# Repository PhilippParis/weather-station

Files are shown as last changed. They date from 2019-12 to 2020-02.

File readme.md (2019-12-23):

# ESP8266 Weather-Station

A simple battery powered Weather-Station using the ESP8266.

Transmits the current temperature periodically via 433MHz (range: ~5meters).  
Uses the same encoding as the 'LaCrosse TX2U Temperature Sensor'.

Publishes the temperature, humidity and pressure to OpenWeatherMap.org.  
Data is buffered in the RTC memory and published once per hour to preserve battery.

## Hardware

### Components

* ESP-12F ESP8266 Module
* LM3671 3.3V Buck Converter Breakout
* Adafruit HTU21D-F Temperature & Humidity Sensor
* BMP180 BOSCH Temperature Pressure Sensor 
* FS1000A 433MHz Transmitter

### Schematics

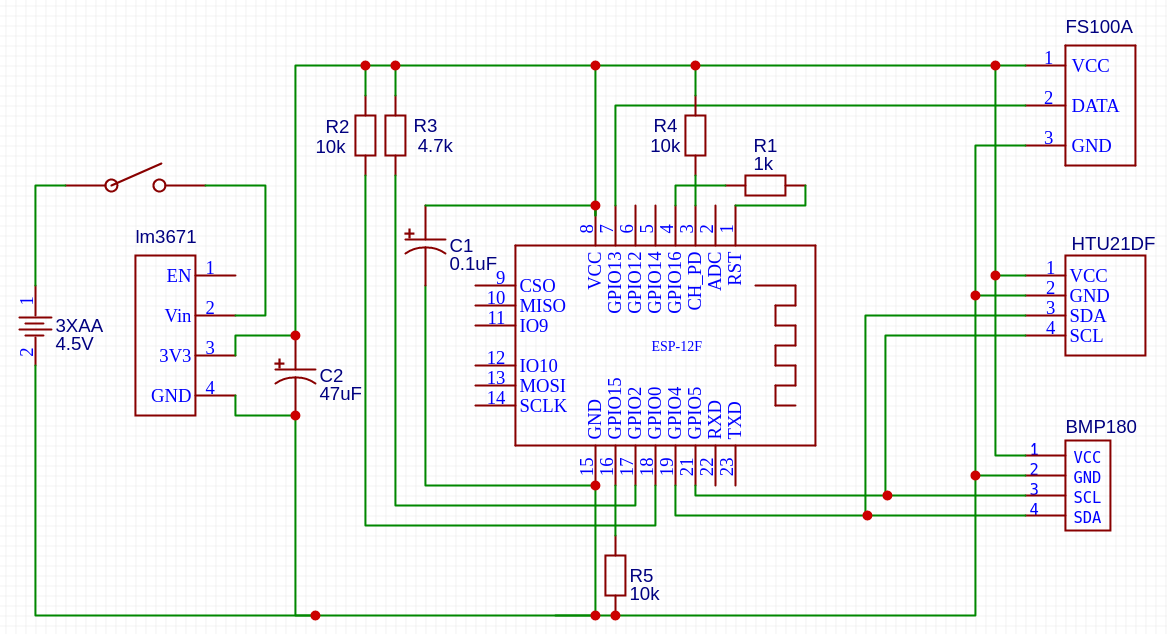
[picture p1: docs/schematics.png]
schematics


## Configuration
### secrets.h

```C++
#define SECRET_WIFI_SSID        "wifi_ssid"
#define SECRET_WIFI_PASSWD      "wifi_password"
#define SECRET_OWM_API_KEY      "open_weather_map_api_key"
#define SECRET_OWM_STATION_ID   "open_weather_map_station_id"
```

## Installation

### Arduino IDE Settings

#### Libaries
* Adafruit BMP085 Unified
* Adafruit HTU21DF Library
* NTPClient

#### Board
Additional Boards Manager URLS: http://arduino.esp8266.com/stable/package_esp8266com_index.json

* Board: Generic ESP8266 Module
* Flash Mode: DIO
* Flash Size: "1MB (FS: 512KB OTA: ~246KB)"

### Programmer Wiring
| Programmer  | ESP12 |
| ---- | --- |
| 3V3  | VCC |
| GND  | GND |
| TXD  | RXD |
| RXD  | TXD |
| GND  | GPIO0 (only when uploading) |

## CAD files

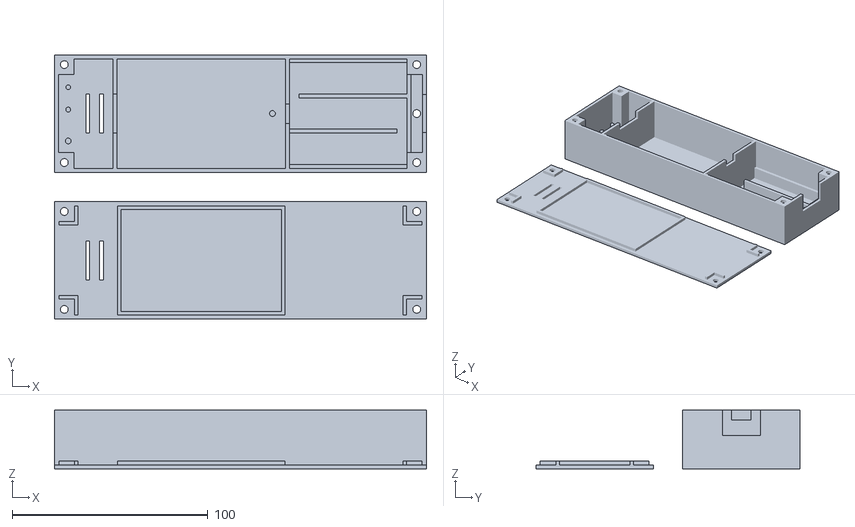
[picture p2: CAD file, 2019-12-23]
docs/case.stl
190.0 x 135.0 x 30.0

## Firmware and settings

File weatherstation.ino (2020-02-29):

#include <ESP8266WiFi.h>
#include <ESP8266HTTPClient.h>
#include <Wire.h>
#include <NTPClient.h>
#include <WiFiUdp.h>

#include "Adafruit_HTU21DF.h"
#include "Adafruit_BMP085_U.h"

#include "Measurement.h"
#include "TX2TempTransmitter.h"
#include "OpenWeatherMap.h"
#include "RTCMemory.h"
#include "secrets.h"

// #define debug

// TX2 TEMPERATURE TRANSMITTER
const uint8_t TX2_SENSOR_ID = 0x20;
const uint8_t TX2_PIN = 13;

// OPEN WEATHER MAP
const uint8_t OWM_BATCH_SIZE = 20;
const char* OWM_API_KEY = SECRET_OWM_API_KEY;
const char* OWM_STATION_ID = SECRET_OWM_STATION_ID;

// WIFI
const char* WIFI_SSID = SECRET_WIFI_SSID;
const char* WIFI_PASSWD = SECRET_WIFI_PASSWD;
const long WIFI_TIMEOUT = 5000;                  // 5 seconds
const IPAddress STATIC_IP(192,168,178,201);
const IPAddress GATEWAY(192,168,178,1);
const IPAddress SUBNET(255,255,255,0);
const IPAddress DNS_1(8,8,8,8);
const IPAddress DNS_2(8,8,4,4);

// OTHER
const long DEEP_SLEEP = 1000000 * 60 * 3;        // 3 minutes

void setup() {  
#ifdef debug
  Serial.begin(19200);
  Serial.setTimeout(2000);
#endif

  println("");
  println("-------------------------------------");
  println("Running Weatherstation Firmware");
  println("-------------------------------------");
  
  pinMode(TX2_PIN, OUTPUT);
  RTCMemory buffer = RTCMemory();
  
  struct Measurement measurement;
  bool success = readFromHTU21DF(measurement.temperature, measurement.humidity);
  success = success && readFromBMP180(measurement.pressure);

  if (success) {
    buffer.add(measurement);
    transmitVia433Mhz(measurement);
    if (buffer.size() >= OWM_BATCH_SIZE) {
      publishToOpenWeatherMap(buffer);
    }
  }
  println("DONE");
  ESP.deepSleep(DEEP_SLEEP, buffer.size() >= (OWM_BATCH_SIZE - 1) ? WAKE_RFCAL : WAKE_RF_DISABLED);
}

void loop() {}

void publishToOpenWeatherMap(RTCMemory &buffer) {
  println("publish to OWM");
  if (connectToWifi(WIFI_SSID, WIFI_PASSWD)) {
    long dt = getEpochTime();
    
    if (dt > 0) {
      for (int i = buffer.size() - 1; i >= 0; i--) {
        buffer.read()[i].dt = dt;
        dt -= DEEP_SLEEP / 1000000;
      }
    
      OpenWeatherMap owm = OpenWeatherMap(OWM_API_KEY, OWM_STATION_ID);
      if (owm.post(buffer.read(), buffer.size())) {
        buffer.clear();
      }
    }
  }
  WiFi.disconnect(true);
}

void transmitVia433Mhz(Measurement measurement) {
  println("transmit via 433Mhz");
  TX2TempTransmitter tx2 = TX2TempTransmitter(TX2_SENSOR_ID, TX2_PIN);
  tx2.transmit(((float) measurement.temperature) / 100.0);
}

long getEpochTime() {
  WiFiUDP ntpUDP;
  NTPClient timeClient(ntpUDP, "pool.ntp.org", 0);
  timeClient.begin();
  if (!timeClient.update()) {
    return -1;
  }
  return timeClient.getEpochTime();
}

bool readFromBMP180(uint16_t &pressure) {
  Adafruit_BMP085_Unified bmp = Adafruit_BMP085_Unified(10085);
  if(!bmp.begin()) {
    println("BMP180 not detected!");
    return false;
  }
  sensors_event_t event;
  bmp.getEvent(&event);
  pressure = (uint16_t) event.pressure;
  return true;
}

bool readFromHTU21DF(int16_t &temperature, uint8_t& humidity) {
  Adafruit_HTU21DF htu = Adafruit_HTU21DF();
  if (!htu.begin()) {
    println("HTU21DF not detected!");
    return false;
  }

  temperature = (int16_t) (htu.readTemperature() * 100.0);
  humidity = (uint8_t) htu.readHumidity();  
  return true;
}

bool connectToWifi(const char* ssid, const char* password) {
  println("Connecting to wifi...");
  WiFi.disconnect(true);
  WiFi.config(STATIC_IP, GATEWAY, SUBNET, DNS_1, DNS_2);
  WiFi.mode(WIFI_STA);
  WiFi.begin(ssid, password);
  
  unsigned long wifiConnectStart = millis();
  while (WiFi.status() != WL_CONNECTED) {
    if (WiFi.status() == WL_CONNECT_FAILED) {
      println("Failed to connect to WiFi");
      return false;
    }

    delay(50);
    if (millis() - wifiConnectStart > WIFI_TIMEOUT) {
      println("Failed to connect to WiFi: timeout");
      return false;
    }
  }
  println("WiFi connected");
  return true;
}

void println(String line) {
#ifdef debug
  Serial.println(line);
#endif
}

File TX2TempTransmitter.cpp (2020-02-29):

#include "TX2TempTransmitter.h"

TX2TempTransmitter::TX2TempTransmitter(uint8_t sensorID, uint8_t pin) {
  this->sensorID = sensorID;
  this->pin = pin;
}

void TX2TempTransmitter::transmit(float temp) {
  uint8_t nibble[11];
  // add 50 degree offset
  temp += 50;

  // preamble
  nibble[0] = TX2_PREAMBLE_1;
  nibble[1] = TX2_PREAMBLE_2;
  nibble[2] = TX2_TYPE_TEMP;
  // temperature
  nibble[5] = nibble[8] = int(temp) / 10;
  nibble[6] = nibble[9] = int(temp) % 10;
  nibble[7] = int(temp * 10.0) % 10;
  // sensor-id and parity
  nibble[3] = sensorID >> 4;
  nibble[4] = sensorID & 0xE | calcParity(nibble);
  //crc
  nibble[10] = calcCRC(nibble);
  
  // send the sequence twice
  for (uint8_t i = 0; i < 2; ++i) { 
    for (uint8_t j = 0; j < 11; j++) {
      sendNibble(nibble[j]);
    }
    delay(20);
  }
}

void TX2TempTransmitter::I() {
  digitalWrite(pin, HIGH); 
  delayMicroseconds(TX2_SHORT_PULSE); 
  digitalWrite(pin, LOW); 
  delayMicroseconds(TX2_DELAY);
}

void TX2TempTransmitter::O() {
  digitalWrite(pin, HIGH); 
  delayMicroseconds(TX2_LONG_PULSE); 
  digitalWrite(pin, LOW); 
  delayMicroseconds(TX2_DELAY); 
}

void TX2TempTransmitter::sendNibble(uint8_t i) {
  if (i&8) I(); else O();
  if (i&4) I(); else O();
  if (i&2) I(); else O();
  if (i&1) I(); else O();
}

uint8_t TX2TempTransmitter::calcCRC(uint8_t nibble[]) {
  int crc = 0;
  for (uint8_t i = 0; i < 10; i++) {
    crc += nibble[i];
  }
  return crc & 0xF;
}

uint8_t TX2TempTransmitter::calcParity(uint8_t nibble[]) {
  uint8_t parity = 0;
  for (uint8_t i = 5; i < 8; i++) {
    parity += nibble[i] & 1;
    parity += nibble[i] >> 1 & 1;
    parity += nibble[i] >> 2 & 1;
    parity += nibble[i] >> 3 & 1;
  }
  return parity & 1;
}

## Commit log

2019-12-28 updated schematics
2020-02-09 fixed TX2 Transmitter protocol
    [TX2TempTransmitter.cpp, TX2TempTransmitter.h]
